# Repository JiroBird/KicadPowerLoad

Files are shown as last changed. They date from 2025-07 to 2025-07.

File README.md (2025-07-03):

The rights to the circuit design belong to: 
https://www.youtube.com/c/akakasyan

The project presents a vision of PCB implementation by JiroBird.

!!! NOTICE !!!!
The project uses a super diode 80EBU02, the cathode of which is directly connected to the drain of the super transistor IRGPS40B120U through cooling plates

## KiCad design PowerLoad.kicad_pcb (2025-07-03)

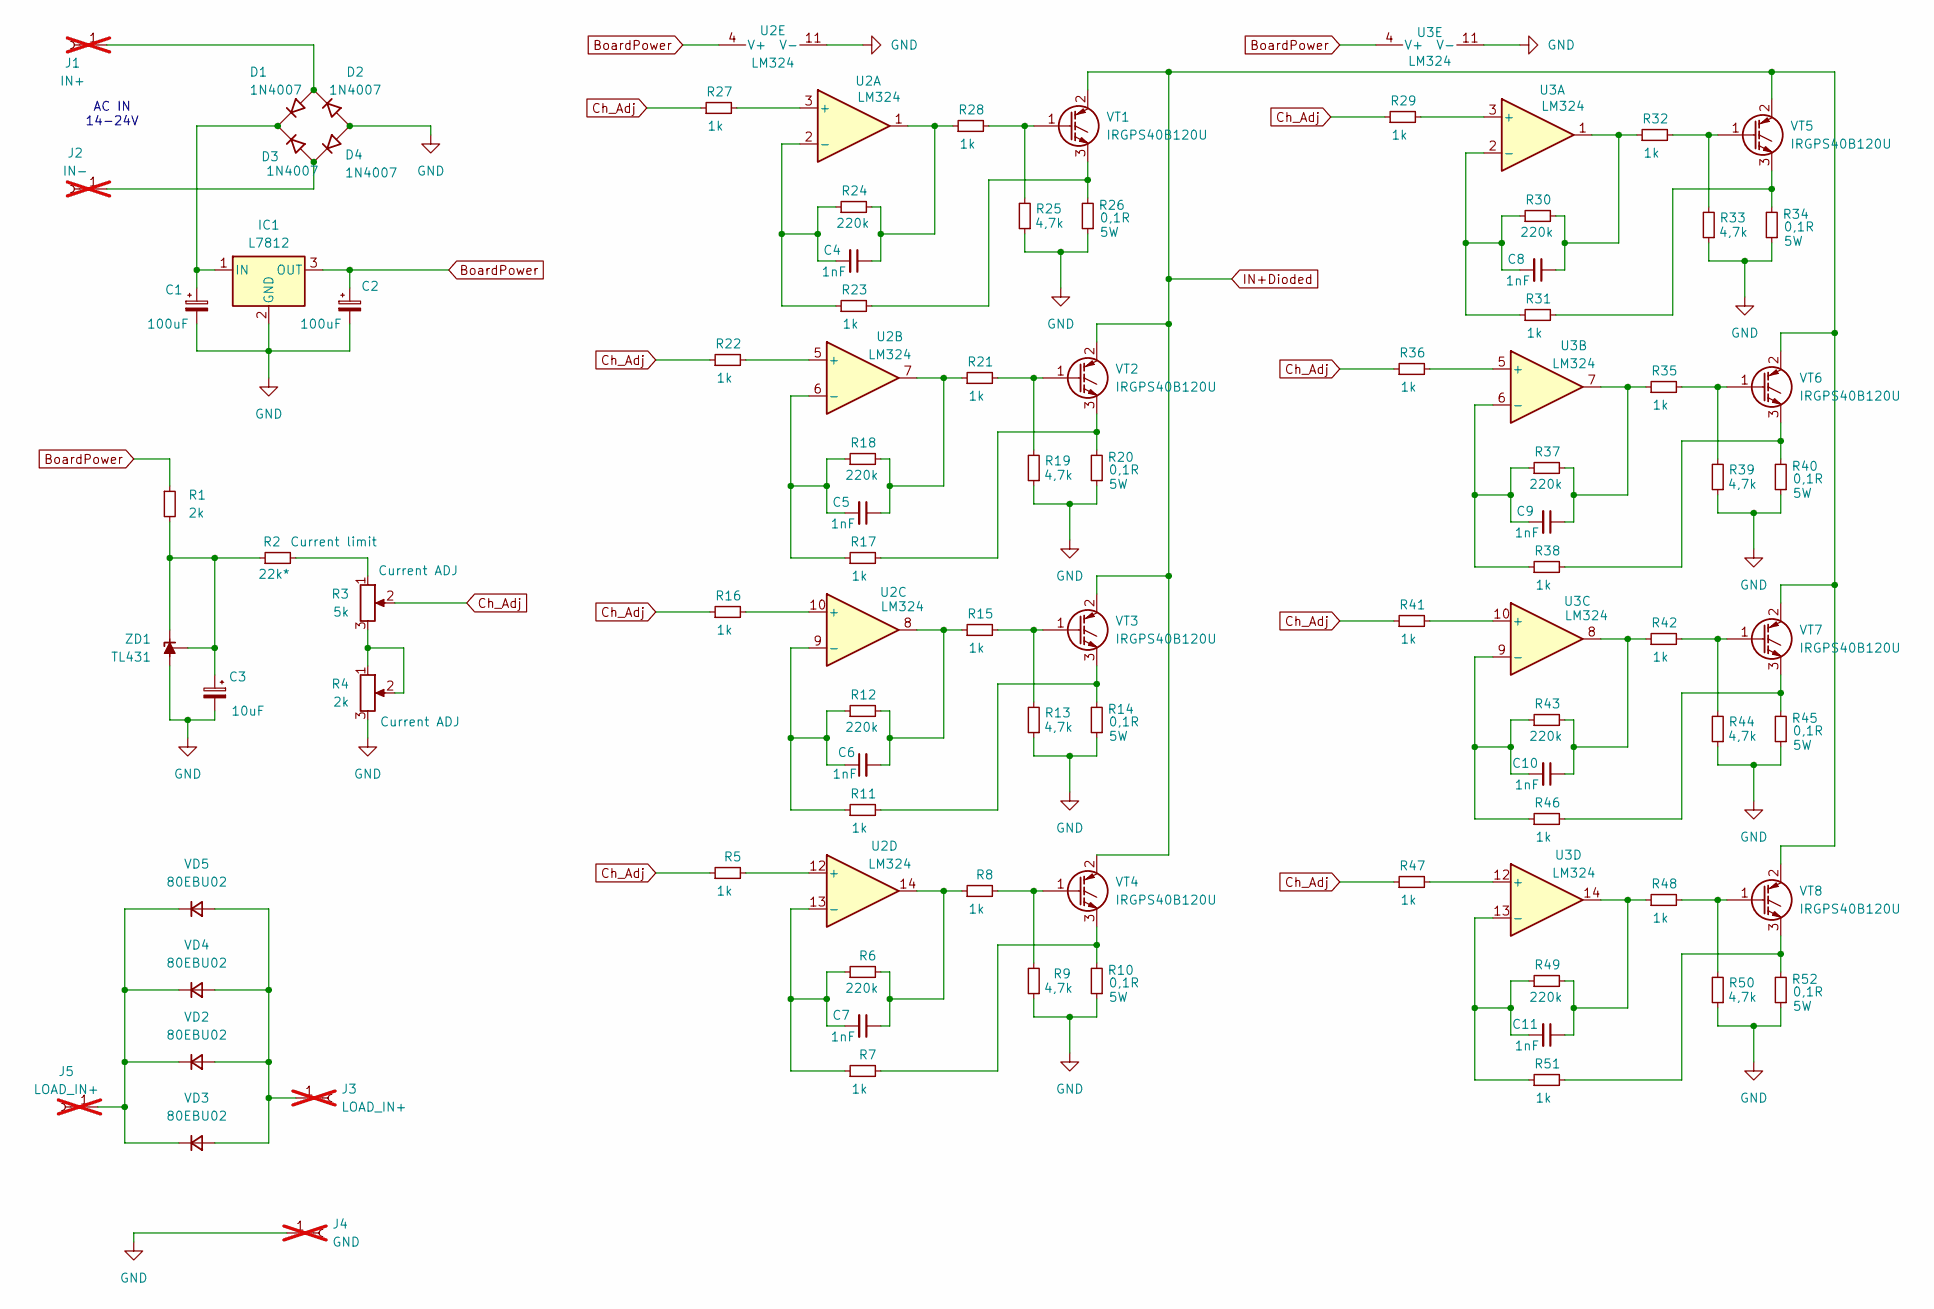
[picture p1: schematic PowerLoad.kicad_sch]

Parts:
C1, C2: 100uF; CP_Radial_D8.0mm_P3.80mm
C3: 10uF; CP_Radial_D5.0mm_P2.50mm
C4, C5, C6, C7, C8, C9, C10, C11: 1nF; C_Axial_L3.8mm_D2.6mm_P7.50mm_Horizontal
D1, D2, D3, D4: 1N4007; D_DO-41_SOD81_P10.16mm_Horizontal
IC1: L7812; TO-220-3_Vertical
J1: IN+; SolderWire-2.5sqmm_1x01_D2.4mm_OD4.4mm; not fitted
J2: IN-; SolderWire-2.5sqmm_1x01_D2.4mm_OD4.4mm; not fitted
J3, J5: LOAD_IN+; SolderWire-16sqmm_1x01_D8.5mm_OD12mm; not fitted
J4: GND; SolderWire-16sqmm_1x01_D8.5mm_OD12mm; not fitted
R1: 2k; R_Axial_DIN0204_L3.6mm_D1.6mm_P7.62mm_Horizontal
R2: 22k*; R_Axial_DIN0204_L3.6mm_D1.6mm_P7.62mm_Horizontal
R3: 5k; Potentiometer_Bourns_3386F_Vertical
R4: 2k; Potentiometer_Bourns_3386F_Vertical
R5, R7, R8, R11, R15, R16, R17, R21, R22, R23, R27, R28, R29, R31, R32, R35, R36, R38, R41, R42, R46, R47, R48, R51: 1k; R_Axial_DIN0204_L3.6mm_D1.6mm_P7.62mm_Horizontal
R6, R12, R18, R24, R30, R37, R43, R49: 220k; R_Axial_DIN0204_L3.6mm_D1.6mm_P7.62mm_Horizontal
R9, R13, R19, R25, R33, R39, R44, R50: 4,7k; R_Axial_DIN0204_L3.6mm_D1.6mm_P7.62mm_Horizontal
R10, R14, R20, R26, R34, R40, R45, R52: 0,1R; R_Axial_DIN0309_L9.0mm_D3.2mm_P25.40mm_Horizontal
U2, U3: LM324; DIP-14_W7.62mm_LongPads
VD2, VD3, VD4, VD5: 80EBU02; TO-247-3(powirtab)
VT1, VT2, VT3, VT4, VT5, VT6, VT7, VT8: IRGPS40B120U; TO-247-3_Vertical
ZD1: TL431; TO-92_Inline

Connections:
BoardPower: C2.1, IC1.3 (OUT), R1.1, U2.4 (V+), U3.4 (V+)
Ch_Adj: R3.2, R5.1, R16.1, R22.1, R27.1, R29.1, R36.1, R41.1, R47.1
GND: C1.2, C2.2, C3.2, D2.2 (A), D4.2 (A), IC1.2 (GND), J4.1, R4.3, R9.1, R10.1, R13.1, R14.1, R19.1, R20.1, R25.1, R26.1, R33.1, R34.1, R39.1, R40.1, R44.1, R45.1, R50.1, R52.1, U2.11 (V-), U3.11 (V-), ZD1.2 (A)
IN+Dioded: VT1.2 (C), VT2.2 (C), VT3.2 (C), VT4.2 (C), VT5.2 (C), VT6.2 (C), VT7.2 (C), VT8.2 (C)
unnamed: C4.1, R24.2, R28.1, U2.1
unnamed: C5.1, R18.2, R21.1, U2.7
unnamed: C6.2, R12.2, R15.1, U2.8
unnamed: C7.1, R6.2, R8.1, U2.14
unnamed: C8.1, R30.2, R32.1, U3.1
unnamed: C9.1, R35.1, R37.2, U3.7
unnamed: C10.1, R42.1, R43.2, U3.8
unnamed: C11.1, R48.1, R49.2, U3.14
unnamed: D1.2 (A), D2.1 (K), J1.1
unnamed: C1.1, D1.1 (K), D3.1 (K), IC1.1 (IN)
unnamed: D3.2 (A), D4.1 (K), J2.1
unnamed: J3.1, VD2.2 (A), VD3.2 (A), VD4.2 (A), VD5.2 (A)
unnamed: J5.1, VD2.1 (K), VD3.1 (K), VD4.1 (K), VD5.1 (K)
unnamed: R2.2, R3.1
unnamed: R3.3, R4.1, R4.2
unnamed: R27.2, U2.3 (+)
unnamed: C4.2, R23.1, R24.1, U2.2 (-)
unnamed: R22.2, U2.5 (+)
unnamed: C5.2, R17.1, R18.1, U2.6 (-)
unnamed: R16.2, U2.10 (+)
unnamed: C6.1, R11.1, R12.1, U2.9 (-)
unnamed: R5.2, U2.12 (+)
unnamed: C7.2, R6.1, R7.1, U2.13 (-)
unnamed: R29.2, U3.3 (+)
unnamed: C8.2, R30.1, R31.1, U3.2 (-)
unnamed: R36.2, U3.5 (+)
unnamed: C9.2, R37.1, R38.1, U3.6 (-)
unnamed: R41.2, U3.10 (+)
unnamed: C10.2, R43.1, R46.1, U3.9 (-)
unnamed: R47.2, U3.12 (+)
unnamed: C11.2, R49.1, R51.1, U3.13 (-)
unnamed: R23.2, R26.2, VT1.3 (E)
unnamed: R25.2, R28.2, VT1.1 (G)
unnamed: R17.2, R20.2, VT2.3 (E)
unnamed: R19.2, R21.2, VT2.1 (G)
unnamed: R11.2, R14.2, VT3.3 (E)
unnamed: R13.2, R15.2, VT3.1 (G)
unnamed: R7.2, R10.2, VT4.3 (E)
unnamed: R8.2, R9.2, VT4.1 (G)
unnamed: R31.2, R34.2, VT5.3 (E)
unnamed: R32.2, R33.2, VT5.1 (G)
unnamed: R38.2, R40.2, VT6.3 (E)
unnamed: R35.2, R39.2, VT6.1 (G)
unnamed: R45.2, R46.2, VT7.3 (E)
unnamed: R42.2, R44.2, VT7.1 (G)
unnamed: R51.2, R52.2, VT8.3 (E)
unnamed: R48.2, R50.2, VT8.1 (G)
unnamed: C3.1, R1.2, R2.1, ZD1.1 (REF), ZD1.3 (K)

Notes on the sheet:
AC IN 14-24V

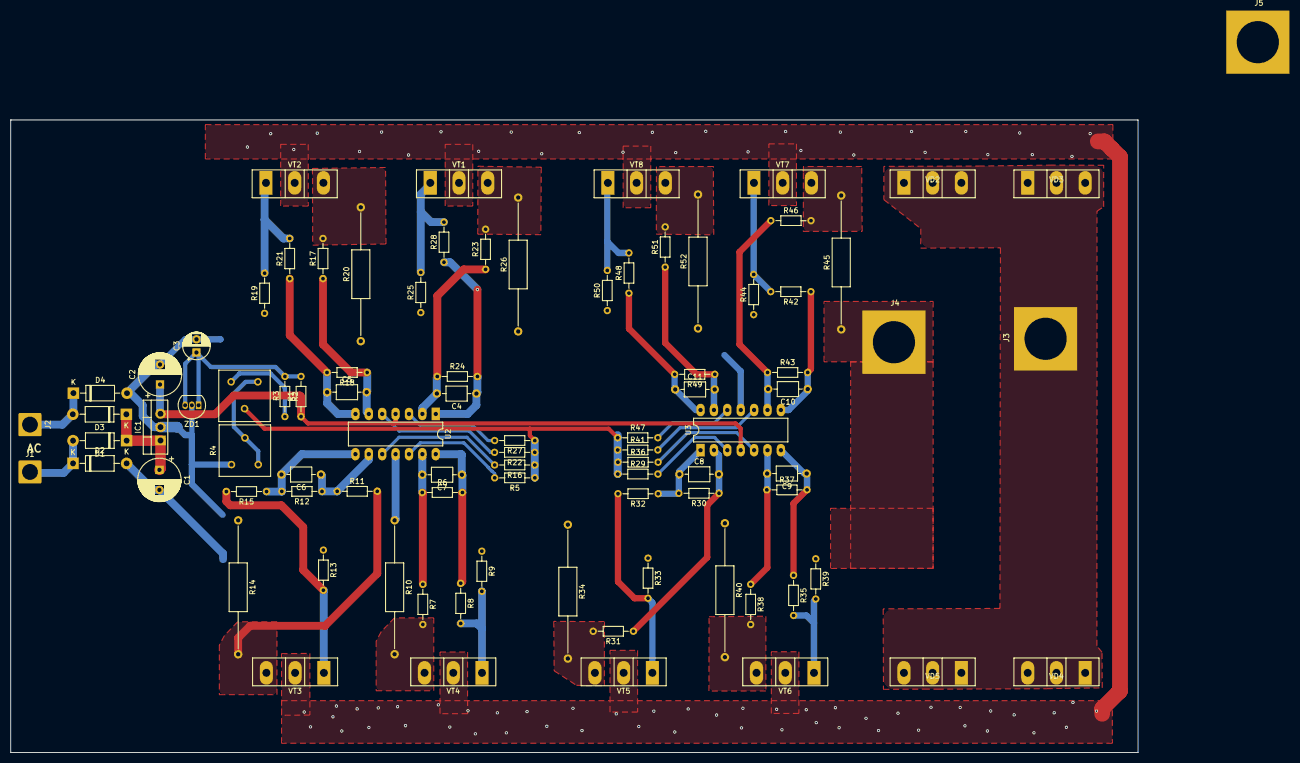
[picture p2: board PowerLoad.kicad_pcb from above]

Board: 2 copper layers, 213.9 x 120.0 mm, 88 parts (0 on the bottom side), 51 nets.
